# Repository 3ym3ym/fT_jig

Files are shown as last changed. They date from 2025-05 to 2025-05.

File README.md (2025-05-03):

Simple jig to measure fT parameter of NPN transistors. 
The idea is from Charles Wenzel : https://techlib.com/newprojects.htm . My twist on it is using fixed frequency rather than variable, and adjust the input amplitude instead, until the RF detector shows a fixed voltage in the middle of its working linear range, let's say 1V. The magic calibration constant in the code is obtained by measuring the RF voltage corresponding to this DC level with a scope.
The 10MHz sine wave of variable amplitude is generated using PIO and R-2R DAC. See https://www.instructables.com/Arbitrary-Wave-Generator-With-the-Raspberry-Pi-Pic/ for details.
The jig works fot fT range of 80MHz (limited by the maximum DAC output) to about 450MHz.

**Instructions:**

 - Install MicroPython on Raspberry Pi Pico. An easy way is to use Thonny.
 - Copy main.py to the Pico root directory. It will be executed on startup.
 - Assemble the jig on a prototyping board with a ground plane (or, better, design and build a real PCB with a good ground plane). If not available, use a regular prototyping board (not a solderless one). Make all connections that carry the RF signal very short. Use a lot of ground wires.
 - Optional: connect the SSD1306 128x64 OLED display to I2C pins if plan to use the device standalone (no computer). It will display the same info as printed in the Thonny shell window.

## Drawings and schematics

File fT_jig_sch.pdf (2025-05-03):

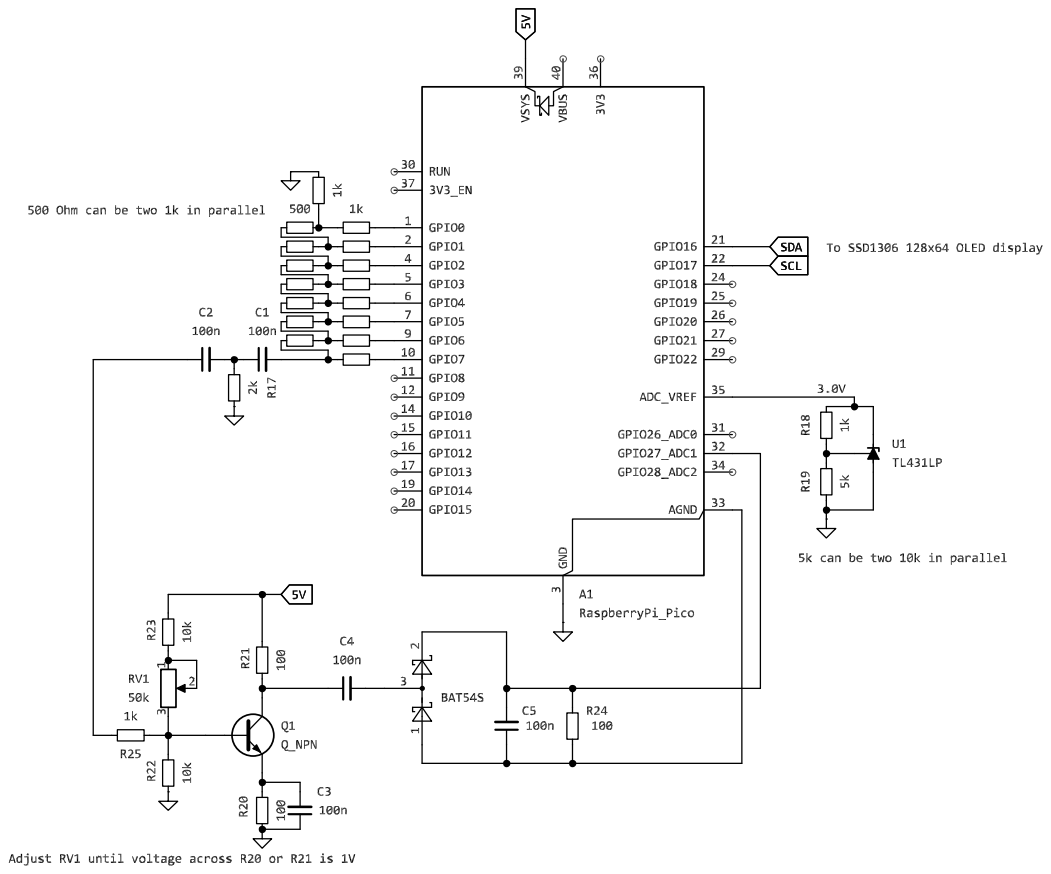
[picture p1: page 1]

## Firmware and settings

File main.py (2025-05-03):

# Arbitrary waveform generator for Rasberry Pi Pico
# Requires 8-bit R2R DAC on pins 0-7. Works for R=1kOhm
# Achieves 125Msps when running 125MHz clock
# Rolf Oldeman, 13/2/2021. CC BY-NC-SA 4.0 licence
# tested with rp2-pico-20210205-unstable-v1.14-8-g1f800cac3.uf2
from machine import Pin,mem32,ADC,I2C
from rp2 import PIO, StateMachine, asm_pio
from array import array
from utime import sleep
from math import pi,sin,exp,sqrt,floor
from uctypes import addressof
from random import random
import ssd1306


fclock=125000000 #clock frequency of the pico
adc = ADC(Pin(27))

i2c = I2C(0, scl=Pin(17), sda=Pin(16), freq=400000)
oled_width = 128
oled_height = 64
oled = ssd1306.SSD1306_I2C(oled_width, oled_height, i2c)
oled.fill(0)
oled.show()


DMA_BASE=0x50000000
CH0_READ_ADDR  =DMA_BASE+0x000
CH0_WRITE_ADDR =DMA_BASE+0x004
CH0_TRANS_COUNT=DMA_BASE+0x008
CH0_CTRL_TRIG  =DMA_BASE+0x00c
CH0_AL1_CTRL   =DMA_BASE+0x010
CH1_READ_ADDR  =DMA_BASE+0x040
CH1_WRITE_ADDR =DMA_BASE+0x044
CH1_TRANS_COUNT=DMA_BASE+0x048
CH1_CTRL_TRIG  =DMA_BASE+0x04c
CH1_AL1_CTRL   =DMA_BASE+0x050

PIO0_BASE      =0x50200000
PIO0_TXF0      =PIO0_BASE+0x10
PIO0_SM0_CLKDIV=PIO0_BASE+0xc8

#state machine that just pushes bytes to the pins
@asm_pio(out_init=(PIO.OUT_HIGH,PIO.OUT_HIGH,PIO.OUT_HIGH,PIO.OUT_HIGH,PIO.OUT_HIGH,PIO.OUT_HIGH,PIO.OUT_HIGH,PIO.OUT_HIGH),
         out_shiftdir=PIO.SHIFT_RIGHT, autopull=True, pull_thresh=32)
def stream():
    out(pins,8)

sm = StateMachine(0, stream, freq=125000000, out_base=Pin(0))
sm.active(1)

#2-channel chained DMA. channel 0 does the transfer, channel 1 reconfigures
p=array('I',[0]) #global 1-element array
def startDMA(ar,nword):
    #first disable the DMAs to prevent corruption while writing
    mem32[CH0_AL1_CTRL]=0
    mem32[CH1_AL1_CTRL]=0
#setup first DMA which does the actual transfer
    mem32[CH0_READ_ADDR]=addressof(ar)
    mem32[CH0_WRITE_ADDR]=PIO0_TXF0
    mem32[CH0_TRANS_COUNT]=nword
    IRQ_QUIET=0x1 #do not generate an interrupt
    TREQ_SEL=0x00 #wait for PIO0_TX0
    CHAIN_TO=1    #start channel 1 when done
    RING_SEL=0
    RING_SIZE=0   #no wrapping
    INCR_WRITE=0  #for write to array
    INCR_READ=1   #for read from array
    DATA_SIZE=2   #32-bit word transfer
    HIGH_PRIORITY=1
    EN=1
    CTRL0=(IRQ_QUIET<<21)|(TREQ_SEL<<15)|(CHAIN_TO<<11)|(RING_SEL<<10)|(RING_SIZE<<9)|(INCR_WRITE<<5)|(INCR_READ<<4)|(DATA_SIZE<<2)|(HIGH_PRIORITY<<1)|(EN<<0)
    mem32[CH0_AL1_CTRL]=CTRL0

#setup second DMA which reconfigures the first channel
    p[0]=addressof(ar)
    mem32[CH1_READ_ADDR]=addressof(p)
    mem32[CH1_WRITE_ADDR]=CH0_READ_ADDR
    mem32[CH1_TRANS_COUNT]=1
    IRQ_QUIET=0x1 #do not generate an interrupt
    TREQ_SEL=0x3f #no pacing
    CHAIN_TO=0    #start channel 0 when done
    RING_SEL=0
    RING_SIZE=0   #no wrapping
    INCR_WRITE=0  #single write
    INCR_READ=0   #single read
    DATA_SIZE=2   #32-bit word transfer
    HIGH_PRIORITY=1
    EN=1
    CTRL1=(IRQ_QUIET<<21)|(TREQ_SEL<<15)|(CHAIN_TO<<11)|(RING_SEL<<10)|(RING_SIZE<<9)|(INCR_WRITE<<5)|(INCR_READ<<4)|(DATA_SIZE<<2)|(HIGH_PRIORITY<<1)|(EN<<0)
    mem32[CH1_CTRL_TRIG]=CTRL1



def setupwave(buf,f,w):
    div=fclock/(f*maxnsamp) # required clock division for maximum buffer size
    if div<1.0:  #can't speed up clock, duplicate wave instead
        dup=int(1.0/div)
        nsamp=int((maxnsamp*div*dup+0.5)/4)*4 #force multiple of 4
        clkdiv=1
    else:        #stick with integer clock division only
        clkdiv=int(div)+1
        nsamp=int((maxnsamp*div/clkdiv+0.5)/4)*4 #force multiple of 4
        dup=1

    #fill the buffer
    for isamp in range(nsamp):
        buf[isamp]=max(0,min(255,int(256*eval(w,dup*(isamp+0.5)/nsamp))))

    #set the clock divider
    clkdiv_int=min(clkdiv,65535) 
    clkdiv_frac=0 #fractional clock division results in jitter
    mem32[PIO0_SM0_CLKDIV]=(clkdiv_int<<16)|(clkdiv_frac<<8)

    #start DMA
    startDMA(buf,int(nsamp/4))


#evaluate the content of a wave
def eval(w,x):
    m,s,p=1.0,0.0,0.0
    if 'phasemod' in w.__dict__:
        p=eval(w.phasemod,x)
    if 'mult' in w.__dict__:
        m=eval(w.mult,x)
    if 'sum' in w.__dict__:
        s=eval(w.sum,x)
    x=x*w.replicate-w.phase-p
    x=x-floor(x)  #reduce x to 0.0-1.0 range
    v=w.func(x,w.pars)
    v=v*w.amplitude*m
    v=v+w.offset+s
    return v

#some common waveforms. combine with sum,mult,phasemod
def sine(x,pars):
    return sin(x*2*pi)
    

#make buffers for the waveform.
#large buffers give better results but are slower to fill
maxnsamp=1024 #must be a multiple of 4. miximum size is 65536
wavbuf={}
wavbuf[0]=bytearray(maxnsamp)
wavbuf[1]=bytearray(maxnsamp)
ibuf=0

#empty class just to attach properties to
class wave:
    pass

while True :
    ampl = 0.05
    for m in range(8) :
        wave1=wave()
        wave1.amplitude=ampl
        wave1.offset=0.5
        wave1.phase=0.0
        wave1.replicate=1
        wave1.func=sine
        wave1.pars=[]

        freq = 1e7
        setupwave(wavbuf[ibuf],freq,wave1); ibuf=(ibuf+1)%2
        v=0
        for i in range(10) :
            v += adc.read_u16()
            sleep(0.01)
        vout = v*3.3/(10*65536)
        print(m,ampl,vout)
        
        oled.fill(0)
        val_str = '{} {} {}'.format(m,ampl,vout)
        oled.text(val_str, 0, 0)
        oled.show()
        
        sar_factor = 1+1.0/2**m
        if (vout<1.0) :
            print("mul by ", sar_factor)
            ampl = ampl * sar_factor
        else :
            print("div by",sar_factor)
            ampl = ampl / sar_factor

    oled.fill(0)
    val_str = 'fT = {:.0f}MHz'.format(freq*4.2e-6/ampl)
    oled.text(val_str, 0, 10)
    oled.show()
    
    print ("fT = ", freq*4.2e-6/ampl)
    sleep(1)

#step through amplitudes
#freq=2e5
#for amp in (0.1,0.2,0.3,0.4,0.5):
#    wave1.amplitude=amp
#    setupwave(wavbuf[ibuf],freq,wave1); ibuf=(ibuf+1)%2
